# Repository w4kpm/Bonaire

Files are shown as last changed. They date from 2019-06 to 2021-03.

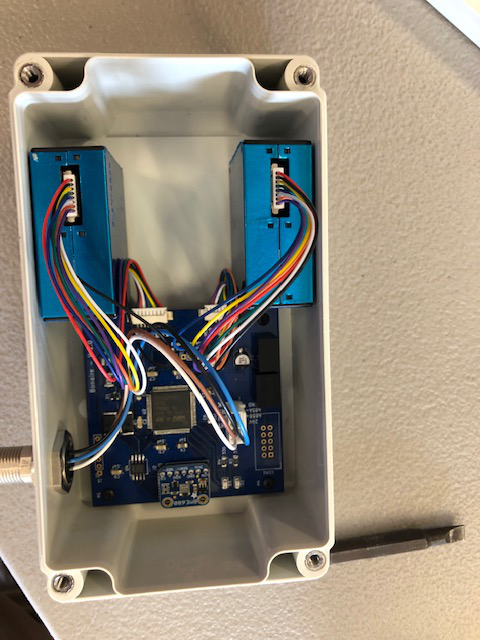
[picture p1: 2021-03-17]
IMG_2014.jpg

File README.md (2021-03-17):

# Bonaire Envronmental Sensor

Particulate Sensor / Pressure /Humidity /VOC sensor

24v / Modbus - inital modbusid = 65 baud = 9600

uses low cost BME680 for pressure, humidity, temp and voc
it also uses 2x pms5003 to measure particulate matter

details about the parameters are in the PDF's of the individual sensors

RS-485 and 24v are hooked up by 1 M12 connector 

modbus registers:

   1: pressure
    
   2: humidity
    
   3: a_pm1_0_atm
    
   4: a_pm2_5_atm
    
   5: a_pm10_0_atm
    
   6: a_pm1_0_cf_1
    
   7: a_pm2_5_cf_1
    
   8: a_pm10_0_cf_1
    
   9: a_p_0_3_um
   
   10: a_p_0_5_um
   
   11: a_p_1_0_um
   
   12: a_p_2_5_um
   
   13: a_p_5_0_um
   
   14: a_p_10_0_um
   
   15: b_pm1_0_atm
   
   16: b_pm2_5_atm
   
   17: b_pm10_0_atm
   
   18: b_pm1_0_cf_1
   
   19: b_pm2_5_cf_1
   
   20: b_pm10_0_cf_1
   
   21: b_p_0_3_um
   
   22: b_p_0_5_um
   
   23: b_p_1_0_um
   
   24: b_p_2_5_um
   
   25: b_p_5_0_um
   
   26: b_p_10_0_um
   
   27: voc
   
   28: temp

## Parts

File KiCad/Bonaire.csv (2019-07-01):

Item | Qty | Reference(s) | Value | LibPart | Footprint | Datasheet
1 | 1 | C1 | 100uF | device:CP1 | Capacitors_SMD:C_1206_HandSoldering
2 | 4 | C2, C4, C6, C8 | 1uF | device:C | Capacitors_SMD:C_1206_HandSoldering
3 | 4 | C3, C5, C7, C9 | .1uF | device:C | Capacitors_SMD:C_1206_HandSoldering
4 | 1 | C10 | .1u | device:C | Capacitors_SMD:C_1206_HandSoldering
5 | 10 | C11, C12, C14, C15, C17, C18, C20, C21, C23, C24 | .1 uF | device:C | Capacitors_SMD:C_1206_HandSoldering
6 | 5 | C13, C16, C19, C22, C25 | 100nF | device:C | Capacitors_SMD:C_1206_HandSoldering
7 | 1 | CON1 | AVR-JTAG-10 | atmel:AVR-JTAG-10 | Pin_Headers:Pin_Header_Straight_2x05_Pitch2.54mm
8 | 8 | D1, D2, D4, D5, D6, D7, D8, D9 | D_Schottky | device:D_Schottky | Diodes_SMD:D_1206
9 | 1 | D3 | D_TVS_x2_AAC | device:D_TVS_x2_AAC | TO_SOT_Packages_SMD:SOT-23_Handsoldering
10 | 4 | F1, F2, F3, F4 | Polyfuse_Small | device:Polyfuse_Small | Resistors_SMD:R_1812_HandSoldering
11 | 6 | J1, J2, J3, J4, J5, J6 | Conn_01x04 | conn:Conn_01x04
12 | 1 | J7 | Conn_01x11 | conn:Conn_01x11 | Pin_Headers:Pin_Header_Straight_1x11_Pitch2.54mm
13 | 1 | J8 | Conn_01x06 | conn:Conn_01x06 | Pin_Headers:Pin_Header_Straight_1x06_Pitch2.54mm
14 | 1 | J9 | Conn_01x09 | conn:Conn_01x09 | Pin_Headers:Pin_Header_Straight_1x09_Pitch2.54mm
15 | 1 | J10 | Conn_01x10 | conn:Conn_01x10 | Pin_Headers:Pin_Header_Straight_1x10_Pitch2.54mm
16 | 1 | J11 | Conn_01x16 | conn:Conn_01x16 | Pin_Headers:Pin_Header_Straight_2x08_Pitch2.54mm
17 | 1 | R1 | 0 | device:R | Capacitors_SMD:C_1206_HandSoldering
18 | 2 | R2, R3 | 10 | device:R | Capacitors_SMD:C_1206_HandSoldering
19 | 1 | R4 | 9k | device:R | Capacitors_SMD:C_1206_HandSoldering
20 | 1 | R5 | 125 | device:R | Capacitors_SMD:C_1206_HandSoldering
21 | 1 | R6 | 1k | device:R | Capacitors_SMD:C_1206_HandSoldering
22 | 1 | R7 | 10k | device:R | Capacitors_SMD:C_1206_HandSoldering
23 | 5 | R8, R9, R10, R11, R12 | 430 .1% | device:R | Capacitors_SMD:C_1206_HandSoldering
24 | 2 | RV1, RV2 | Varistor | device:Varistor | Resistors_SMD:R_1210_HandSoldering
25 | 1 | U1 | LM78l33_TO220 | regul:LM7812_TO220 | TO_SOT_Packages_THT:TO-220-3_Vertical
26 | 1 | U2 | STM32F303V(B-C)Tx_u | stm32:STM32F303V(B-C)Tx_u | Housings_QFP:LQFP-100_14x14mm_Pitch0.5mm
27 | 1 | U3 | SN65HV7X | MyParts:SN65HV7X | Housings_SOIC:SO-8_5.3x6.2mm_Pitch1.27mm
28 | 5 | U4, U5, U6, U7, U8 | MAX31865 | MyParts:MAX31865 | Housings_SSOP:SSOP-20_5.3x7.2mm_Pitch0.65mm

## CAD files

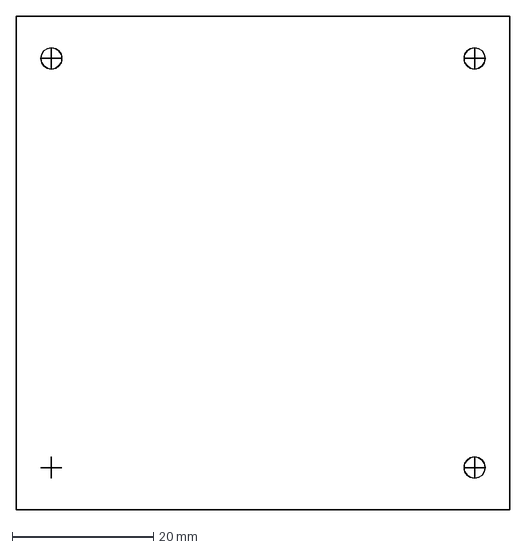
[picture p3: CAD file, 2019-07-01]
KiCad/BonaireOutline.dxf
70.0 x 70.0 mm

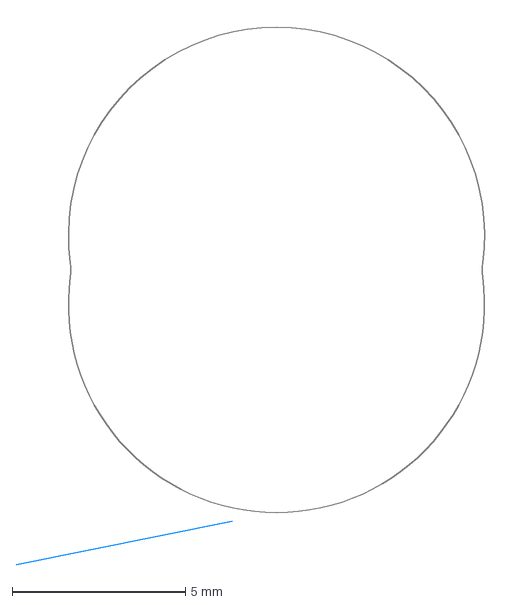
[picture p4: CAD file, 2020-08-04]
M12Hole.dxf
13.8 x 15.8 mm

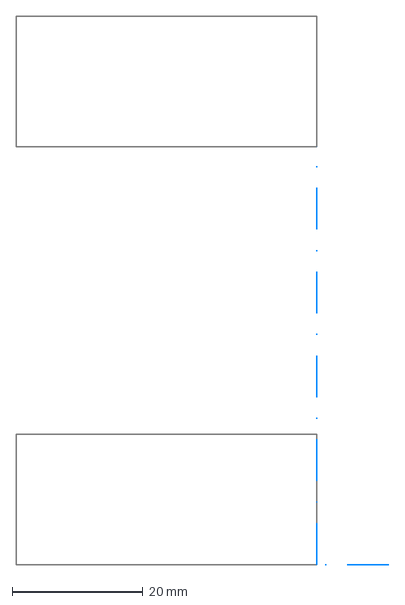
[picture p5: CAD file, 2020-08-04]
SensorCut.dxf
57.0 x 84.0 mm

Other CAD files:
KiCad/kicad-footprints/Sources/Package_SON/X2SON-4_1x1mm_P0.65mm.fcstd
KiCad/kicad-footprints/Sources/Package_TO_SOT_THT/sod-70.fcstd
KiCad/kicad-footprints/Sources/Package_TO_SOT_THT/sod-70_P5.08mm.fcstd

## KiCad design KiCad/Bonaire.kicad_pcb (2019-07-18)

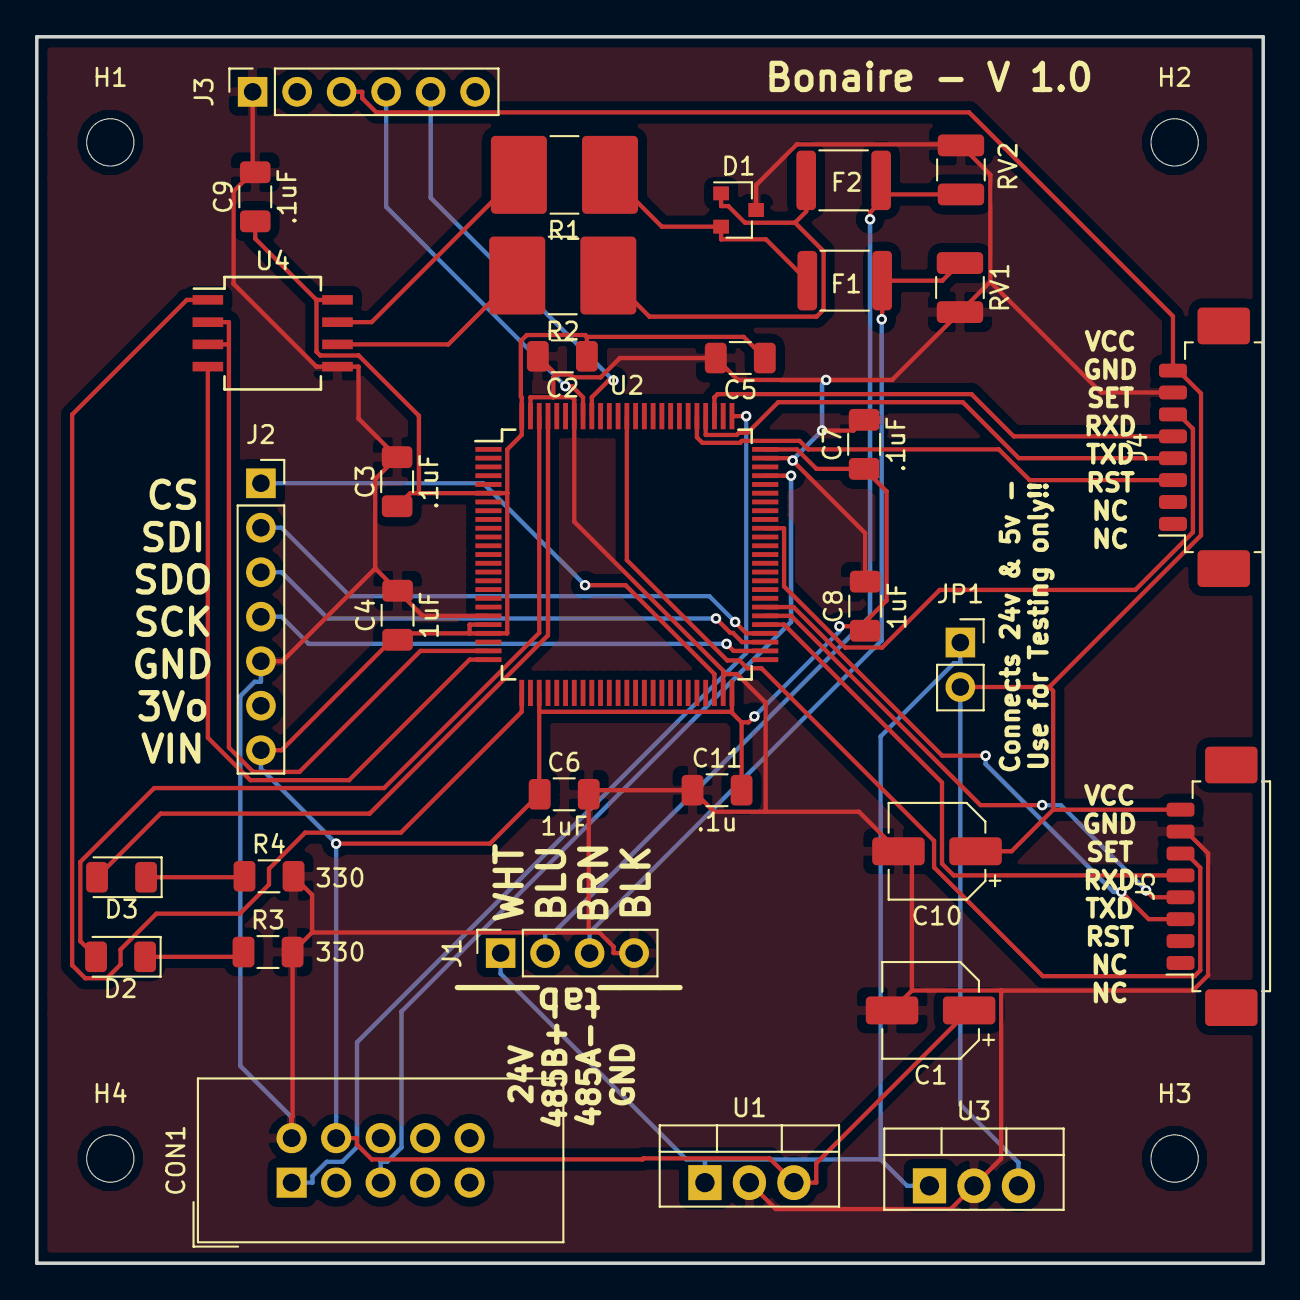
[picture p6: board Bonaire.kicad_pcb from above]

Board: 2 copper layers, 70.0 x 70.0 mm, 37 parts (0 on the bottom side), 33 nets.

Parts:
C1, C10: 100uF; CP_Elec_5x5.3
C2, C4, C6, C8: 1uF; C_1206_3216Metric
C3, C5, C7, C9: .1uF; C_1206_3216Metric
C11: .1u; C_1206_3216Metric
CON1: AVR-JTAG-10; IDC-Header_2x05_P2.54mm_Vertical
D1: D_TVS_x2_AAC; SOT-23
D2, D3: LED; LED_1206_3216Metric
F1, F2: Polyfuse_Small; R_1812_4532Metric
H1, H2, H3, H4: MountingHole; MountingHole_2.7mm_M2.5
J1: Conn_01x04; PinSocket_1x04_P2.54mm_Vertical
J2: Conn_01x07; PinSocket_1x07_P2.54mm_Vertical
J3: Conn_01x06; PinSocket_1x06_P2.54mm_Vertical
J4, J5: Conn_01x08; Molex_PicoBlade_53261-0871_1x08-1MP_P1.25mm_Horizontal
JP1: Jumper; PinSocket_1x02_P2.54mm_Vertical
R1, R2: 10; R_2816_7142Metric_Pad3.20x4.45mm_HandSolder
R3, R4: 330; R_1206_3216Metric
RV1, RV2: Varistor; R_1210_3225Metric
U1: LM78l33_TO220; TO-220-3_Vertical
U2: STM32F303V(B-C)Tx_u; LQFP-100_14x14mm_P0.5mm
U3: LM78l50_TO220; TO-220-3_Vertical
U4: SN65HV7X; SO-8_5.3x6.2mm_P1.27mm

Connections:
+3V3: C1.1, C2.1, C3.1, C4.1, C5.1, C6.1, C7.1, C8.1, C9.1, C11.2, CON1.4, J2.7, U1.3, U2.6, U2.21, U2.22, U2.28, U2.50, U2.75, U2.100, U4.8
+5V: C10.1, J3.3, J4.8, J5.8, JP1.2, U3.3
+24V: J1.1, JP1.1, U1.1, U3.1
/GPIOA/serial/RX: U2.26, U4.1
/GPIOA/serial/TX: U2.25, U4.4
/GPIOA/serial/TX_en: U2.24, U4.2, U4.3
/GPIOB/MISO: J2.3, U2.53
/GPIOB/MOSI: J2.2, U2.54
/GPIOB/SCK: J2.4, U2.52
/GPIOB/UART1_RX: J3.4, U2.93
/GPIOB/UART1_TX: J3.5, U2.92
/GPIOB/~CS: J2.1, U2.48
/RS485A: F2.1, J1.2, RV2.1
/RS485B: F1.1, J1.3, RV1.1
GND: C1.2, C2.2, C3.2, C4.2, C5.2, C6.2, C7.2, C8.2, C9.2, C10.2, C11.1, CON1.2, D1.3, J1.4, J2.5, J3.1, J4.7, J5.7, R3.2, R4.2, RV1.2, RV2.2, U1.2, U2.20, U2.49, U2.74, U2.94, U2.99, U3.2, U4.5
unnamed: CON1.1, U2.76
unnamed: CON1.5, U2.72
unnamed: D1.1, F2.2, R2.1
unnamed: D1.2, F1.2, R1.1
unnamed: D2.1, R3.1
unnamed: D2.2, U2.98
unnamed: D3.1, R4.1
unnamed: D3.2, U2.97
unnamed: J4.3, U2.80
unnamed: J4.4, U2.79
unnamed: J4.5, U2.78
unnamed: J4.6, U2.66
unnamed: J5.3, U2.57
unnamed: J5.4, U2.56
unnamed: J5.5, U2.55
unnamed: J5.6, U2.88
unnamed: R1.2, U4.7
unnamed: R2.2, U4.6

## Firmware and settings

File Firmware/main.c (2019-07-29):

// internal reference voltage calibration  0x1FFF F7BA - 0x1FFF F7BB

// TS_CAL1 TS_CAL2 = 0x1FFF F7B8 - 0x1FFF F7B9 and 0x1FFF F7C2 - 0x1FFF F7C3




/*
    ChibiOS - Copyright (C) 2006..2015 Giovanni Di Sirio

    Licensed under the Apache License, Version 2.0 (the "License");
    you may not use this file except in compliance with the License.
    You may obtain a copy of the License at

        http://www.apache.org/licenses/LICENSE-2.0

    Unless required by applicable law or agreed to in writing, software
    distributed under the License is distributed on an "AS IS" BASIS,
    WITHOUT WARRANTIES OR CONDITIONS OF ANY KIND, either express or implied.
    See the License for the specific language governing permissions and
    limitations under the License.
*/

#define CHPRINTF_USE_FLOAT   TRUE
#include "ch.h"
#include "hal.h"
#include "stdio.h"
#include "string.h"
#include "stdlib.h"
#include "math.h"
//#include "chprintf.h"
#include "hal_queues.h"
#include <string.h>
#include "stm32f3xx.h"
//#include "font.h"
//#include "fontbig.h"
#include "bme680.h"


static uint8_t txbuf[32];
static uint8_t rxbuf[32];
static uint8_t my_address;
static uint8_t save_address;
static uint8_t baud_rate;
static uint8_t save_baud_rate;
static uint8_t reset =0;

static char text[255];
static char metrics[9][12];

static uint8_t vbuf2[32][33];
static uint8_t vbuf[32][33];


static uint16_t *flash1 = 0x803F000;
static uint16_t *flash2 = 0x803e800;
static uint16_t settings;


static  uint16_t a_pm1_0_atm,
  a_pm2_5_atm,
  a_pm10_0_atm,
  a_pm1_0_cf_1,
  a_pm2_5_cf_1,
  a_pm10_0_cf_1,
  a_p_0_3_um,
  a_p_0_5_um,
  a_p_1_0_um,
  a_p_2_5_um,
  a_p_5_0_um,
  a_p_10_0_um;


static  uint16_t b_pm1_0_atm,
  b_pm2_5_atm,
  b_pm10_0_atm,
  b_pm1_0_cf_1,
  b_pm2_5_cf_1,
  b_pm10_0_cf_1,
  b_p_0_3_um,
  b_p_0_5_um,
  b_p_1_0_um,
  b_p_2_5_um,
  b_p_5_0_um,
  b_p_10_0_um;

static uint16_t humidity,pressure,voc,temp;


#define ADC_GRP1_NUM_CHANNELS   2
#define ADC_GRP2_NUM_CHANNELS   6
#define ADC_GRP1_BUF_DEPTH      1
#define ADC_GRP2_BUF_DEPTH      1
static adcsample_t samples1[ADC_GRP1_NUM_CHANNELS * ADC_GRP1_BUF_DEPTH];
static adcsample_t samples2[ADC_GRP2_NUM_CHANNELS * ADC_GRP2_BUF_DEPTH];
size_t nx = 0, ny = 0;



#define RST 12
#define SPISELECT 11
#define CK 13
#define MISO 14
#define MOSI 15
#define DC 14

struct bme680_dev gas_sensor;







static const SPIConfig std_spicfg3 = {
  NULL,
  NULL,
  GPIOB,                                                        /*port of CS  */
  SPISELECT,                                                /*pin of CS   */
  //SPI_CR1_CPOL|	SPI_CR1_CPHA |		\
  //SPI_CR1_SPE|SPI_CR1_MSTR|SPI_CR1_BR_2,SPI_CR1_BR_1,
  0,
  SPI_CR2_DS_2 | SPI_CR2_DS_1 | SPI_CR2_DS_0                    /*CR2 register*/
};




void unlock_flash()
{
    if (FLASH->CR & FLASH_CR_LOCK){
	FLASH->KEYR = 0x45670123;
	FLASH->KEYR = 0xCDEF89AB;
    }


}


void erase_flash(uint16_t *flash)
{
    int x;
    unlock_flash();                        // must unlock flash before
					   // any write operations

    FLASH->CR |= FLASH_CR_PER;             // set page erase
    
    FLASH->AR = flash;                     // set page to flash
    
    FLASH->CR |= FLASH_CR_STRT;            // start erasing
    
    while ((FLASH->SR & FLASH_SR_BSY) == FLASH_SR_BSY); // loop till done
							// watchdog should
							// reset if it gets
							// stuck

    SET_BIT (FLASH->SR, (FLASH_SR_EOP));   // tech note RM0316 says to clear
    CLEAR_BIT (FLASH->CR, (FLASH_CR_PER)); // found note online that you must
                                           // clear this prior to writing
    
}


void write_flash(uint16_t value,uint16_t* flash)
{
    int x;
    erase_flash(flash);


      
    SET_BIT(FLASH->CR, (FLASH_CR_PG));     // we are already unlocked, trying
					   // to do it again will mess
					   // things up
    
    *flash = value;                        // actually write the value

    
    while ((FLASH->SR & FLASH_SR_BSY) == FLASH_SR_BSY); // loop till done
							// watchdog should
							// reset if it gets
							// stuck
    //  CLEAR_BIT (FLASH->CR, (FLASH_CR_PG));  // probably don't need to to this
					   // again
    
    //SET_BIT (FLASH->SR, (FLASH_SR_EOP));   // tech note RM0316 says to clear
    FLASH->CR |= FLASH_CR_LOCK;
}










void spi_write(location,data)
{
  //palClearPad(GPIOB,SPISELECT);
    spiStart(&SPID2,&std_spicfg3);
    spiSelect(&SPID2);
    txbuf[0] = location;
    txbuf[1] = data;
    spiSend(&SPID2,2,&txbuf);
    spiUnselect(&SPID2);
    spiStop(&SPID2);
    //palSetPad(GPIOB,SPISELECT);
}

uint8_t spi_read(location)
{
  //    palClearPad(GPIOB,SPISELECT);
    spiStart(&SPID2,&std_spicfg3);
    spiSelect(&SPID2);
    txbuf[0] = location | 0x80;
    spiSend(&SPID2,1,&txbuf);
    spiReceive(&SPID2,1,&rxbuf);
    spiUnselect(&SPID2);
    spiStop(&SPID2);
    //   palSetPad(GPIOB,SPISELECT);
    return rxbuf[0];
}


void init_spi()
{

  //  palSetPadMode(GPIOB, RST, PAL_MODE_OUTPUT_PUSHPULL);
  //palSetPadMode(GPIOB, DC, PAL_MODE_OUTPUT_PUSHPULL);
  palSetPadMode(GPIOB, SPISELECT, PAL_MODE_OUTPUT_PUSHPULL);
  palSetPad(GPIOB,SPISELECT);
  //palSetPad(GPIOB,RST);

}










// this should set a timeout of .625 seconds (LSI = 40k / (64 * 1000))

static const WDGConfig wdgcfg = {
  STM32_IWDG_PR_64,
  STM32_IWDG_RL(2000),
  STM32_IWDG_WIN_DISABLED};

// This got redefined in a later version of Chibios for this board
#define GPIOA_PIN0 0



//static uint8_t vbuf[64][128];
//static uint8_t vbuf2[64][128];

static mailbox_t RxMbx;
static mailbox_t RxMbx2;
static mailbox_t RxMbx3;
#define MAILBOX_SIZE 25
static msg_t RxMbxBuff[MAILBOX_SIZE];
static msg_t RxMbxBuff2[MAILBOX_SIZE];
static msg_t RxMbxBuff3[MAILBOX_SIZE];
static char current_key;
static  uint16_t step =0;
static  int16_t deg,speed =0;

static char rx_text[32][48];
static char rx_text2[8][48];
static char rx_text3[8][48];
static int8_t heatValue;
static uint8_t res_heat_x;
static uint8_t heatRange;
static double par_g1,par_g2,par_g3,var1,var2,var3,var4,var5,target_temp,amb_temp,res_heat_range,res_heat_val;
static SerialConfig uartCfg =
{
    115200,// bit rate
    0,
    0,
    0,
};


//static SerialConfig uartCfg2 =
//{
//    19200,// bit rate
//    0x1400,
//    0,
//    0,
//};
//

static SerialConfig uartCfg2 =
{
    9600,// bit rate
    0,
    0,
    0,
};



static SerialConfig uartCfg3 =
{
    19200,// bit rate
    0,
    0,
    0,
};


dbg(char *string)
{
    chprintf((BaseSequentialStream*)&SD1,string);
    chThdSleepMilliseconds(100);
}


/*
 * Application entry point.
 */


/* ******************
stolen from http://www.modbustools.com/modbus.html#crc
*/
uint16_t CRC16 (const char *nData, uint16_t wLength)
{
static const uint16_t wCRCTable[] = {
   0X0000, 0XC0C1, 0XC181, 0X0140, 0XC301, 0X03C0, 0X0280, 0XC241,
   0XC601, 0X06C0, 0X0780, 0XC741, 0X0500, 0XC5C1, 0XC481, 0X0440,
   0XCC01, 0X0CC0, 0X0D80, 0XCD41, 0X0F00, 0XCFC1, 0XCE81, 0X0E40,
   0X0A00, 0XCAC1, 0XCB81, 0X0B40, 0XC901, 0X09C0, 0X0880, 0XC841,
   0XD801, 0X18C0, 0X1980, 0XD941, 0X1B00, 0XDBC1, 0XDA81, 0X1A40,
   0X1E00, 0XDEC1, 0XDF81, 0X1F40, 0XDD01, 0X1DC0, 0X1C80, 0XDC41,
   0X1400, 0XD4C1, 0XD581, 0X1540, 0XD701, 0X17C0, 0X1680, 0XD641,
   0XD201, 0X12C0, 0X1380, 0XD341, 0X1100, 0XD1C1, 0XD081, 0X1040,
   0XF001, 0X30C0, 0X3180, 0XF141, 0X3300, 0XF3C1, 0XF281, 0X3240,
   0X3600, 0XF6C1, 0XF781, 0X3740, 0XF501, 0X35C0, 0X3480, 0XF441,
   0X3C00, 0XFCC1, 0XFD81, 0X3D40, 0XFF01, 0X3FC0, 0X3E80, 0XFE41,
   0XFA01, 0X3AC0, 0X3B80, 0XFB41, 0X3900, 0XF9C1, 0XF881, 0X3840,
   0X2800, 0XE8C1, 0XE981, 0X2940, 0XEB01, 0X2BC0, 0X2A80, 0XEA41,
   0XEE01, 0X2EC0, 0X2F80, 0XEF41, 0X2D00, 0XEDC1, 0XEC81, 0X2C40,
   0XE401, 0X24C0, 0X2580, 0XE541, 0X2700, 0XE7C1, 0XE681, 0X2640,
   0X2200, 0XE2C1, 0XE381, 0X2340, 0XE101, 0X21C0, 0X2080, 0XE041,
   0XA001, 0X60C0, 0X6180, 0XA141, 0X6300, 0XA3C1, 0XA281, 0X6240,
   0X6600, 0XA6C1, 0XA781, 0X6740, 0XA501, 0X65C0, 0X6480, 0XA441,
   0X6C00, 0XACC1, 0XAD81, 0X6D40, 0XAF01, 0X6FC0, 0X6E80, 0XAE41,
   0XAA01, 0X6AC0, 0X6B80, 0XAB41, 0X6900, 0XA9C1, 0XA881, 0X6840,
   0X7800, 0XB8C1, 0XB981, 0X7940, 0XBB01, 0X7BC0, 0X7A80, 0XBA41,
   0XBE01, 0X7EC0, 0X7F80, 0XBF41, 0X7D00, 0XBDC1, 0XBC81, 0X7C40,
   0XB401, 0X74C0, 0X7580, 0XB541, 0X7700, 0XB7C1, 0XB681, 0X7640,
   0X7200, 0XB2C1, 0XB381, 0X7340, 0XB101, 0X71C0, 0X7080, 0XB041,
   0X5000, 0X90C1, 0X9181, 0X5140, 0X9301, 0X53C0, 0X5280, 0X9241,
   0X9601, 0X56C0, 0X5780, 0X9741, 0X5500, 0X95C1, 0X9481, 0X5440,
   0X9C01, 0X5CC0, 0X5D80, 0X9D41, 0X5F00, 0X9FC1, 0X9E81, 0X5E40,
   0X5A00, 0X9AC1, 0X9B81, 0X5B40, 0X9901, 0X59C0, 0X5880, 0X9841,
   0X8801, 0X48C0, 0X4980, 0X8941, 0X4B00, 0X8BC1, 0X8A81, 0X4A40,
   0X4E00, 0X8EC1, 0X8F81, 0X4F40, 0X8D01, 0X4DC0, 0X4C80, 0X8C41,
   0X4400, 0X84C1, 0X8581, 0X4540, 0X8701, 0X47C0, 0X4680, 0X8641,
   0X8201, 0X42C0, 0X4380, 0X8341, 0X4100, 0X81C1, 0X8081, 0X4040 };

char nTemp;
uint16_t wCRCWord = 0xFFFF;

   while (wLength--)
   {
      nTemp = *nData++ ^ wCRCWord;
      wCRCWord >>= 8;
      wCRCWord  ^= wCRCTable[nTemp];
   }
   return wCRCWord;
} // End: CRC16




// Modbus Serial Capture
static THD_WORKING_AREA(waThread3, 512);
static THD_FUNCTION(Thread3, arg) {
  (void)arg;
  int pass = 0;
  msg_t b = 0;
  int rx_queue_pos=0;
  int rx_queue_num=0;

  chRegSetThreadName("serial");
  while(TRUE)
      {
	  
	  b = sdGetTimeout(&SD2,TIME_MS2I(2));

	  if ((b!= Q_TIMEOUT) && (rx_queue_pos < 32))
	      {
		
		  rx_text[rx_queue_num][rx_queue_pos++]=b;
	       
		
	      }
	  if ((b == Q_TIMEOUT) && (rx_queue_pos > 0))
	      {

		  rx_text[rx_queue_num][rx_queue_pos] = 0;
		  chprintf((BaseSequentialStream*)&SD1,"sent One: %d,%d\r\n",rx_queue_num,rx_queue_pos);  
		  chMBPostTimeout(&RxMbx,(rx_queue_num<<8)|rx_queue_pos,TIME_INFINITE); // let our mailbox know
		  chMBPostTimeout(&RxMbx2,(rx_queue_num<<8),TIME_INFINITE); // let our mailbox know
		  rx_queue_pos = 0;
		  // we have a new entry
		  rx_queue_num = (++rx_queue_num)%32;
		  memset(rx_text[rx_queue_num],0,5);
	      }
	  
  
      }

  return MSG_OK;
}

// Particulate Sensor 1 capture
static THD_WORKING_AREA(waThread6, 512);
static THD_FUNCTION(Thread6, arg) {
  (void)arg;
  int pass = 0;
  msg_t b = 0;
  int rx_queue_pos=0;
  int rx_queue_num=0;

  chRegSetThreadName("part1");
  while(TRUE)
      {
	  
	  b = sdGetTimeout(&SD3,TIME_MS2I(5));


	  if ((b!= Q_TIMEOUT) && (rx_queue_pos < 32))
	      {
		
		//chprintf((BaseSequentialStream*)&SD2,"got char: %x\r\n",b);

		rx_text2[rx_queue_num][rx_queue_pos++]=b;
		
		
		

		
	      }
	  if ((b == Q_TIMEOUT) && (rx_queue_pos > 0))
	      {

		  rx_text2[rx_queue_num][rx_queue_pos] = 0;

		  chMBPostTimeout(&RxMbx3,(rx_queue_num<<8),TIME_INFINITE); // let our mailbox know
		  //chMBPostTimeout(&RxMbx2,(rx_queue_num<<8),TIME_INFINITE); // let our mailbox know
		  rx_queue_pos = 0;
		  // we have a new entry
		  rx_queue_num = (++rx_queue_num)%8;
		  memset(rx_text2[rx_queue_num],0,5);
	      }
	  
  
      }

  return MSG_OK;
}

// Particulate Sensor 2 capture
static THD_WORKING_AREA(waThread7, 512);
static THD_FUNCTION(Thread7, arg) {
  (void)arg;
  int pass = 0;
  msg_t b = 0;
  int rx_queue_pos=0;
  int rx_queue_num=0;

  chRegSetThreadName("part2");
  while(TRUE)
      {
	  
	  b = sdGetTimeout(&SD4,TIME_MS2I(5));


	  if ((b!= Q_TIMEOUT) && (rx_queue_pos < 32))
	      {

		  rx_text3[rx_queue_num][rx_queue_pos++]=b;		
	      }
	  if ((b == Q_TIMEOUT) && (rx_queue_pos > 0))
	      {

		  rx_text3[rx_queue_num][rx_queue_pos] = 0;
		  chMBPostTimeout(&RxMbx3,(rx_queue_num<<8)|0x1,TIME_INFINITE); // let our mailbox know
		  rx_queue_pos = 0;
		  // we have a new entry
		  rx_queue_num = (++rx_queue_num)%8;
		  memset(rx_text3[rx_queue_num],0,5);
	      }
	  
  
      }

  return MSG_OK;
}
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
int main(void) {
  unsigned i;

  /*
   * System initializations.
   * - HAL initialization, this also initializes the configured device drivers
   *   and performs the board-specific initializations.
   * - Kernel initialization, the main() function becomes a thread and the
   *   RTOS is active.
   */
  halInit();
  chSysInit();
 

  
  palSetPad(GPIOB, 5);
  wdgStart(&WDGD1, &wdgcfg);
  wdgReset(&WDGD1);
  chMBObjectInit(&RxMbx,&RxMbxBuff,MAILBOX_SIZE);
  chMBObjectInit(&RxMbx2,&RxMbxBuff2,MAILBOX_SIZE);
  chMBObjectInit(&RxMbx3,&RxMbxBuff3,MAILBOX_SIZE);
  adcStart(&ADCD1, NULL);
  //  adcStart(&ADCD4, NULL);
  // I think this needs to go after the start - even though it worked fine before

  // I had a problem in another context
  adcSTM32EnableTSVREFE();
  adcSTM32EnableTS(&ADCD1);
  



  /*
   * SPI1 I/O pins setup.
   */



  palSetPadMode(GPIOE, 0, PAL_MODE_OUTPUT_PUSHPULL);
  palSetPadMode(GPIOE, 1, PAL_MODE_OUTPUT_PUSHPULL);    

  palSetPadMode(GPIOB, 6, PAL_MODE_ALTERNATE(7));  //USART1 - console  
  palSetPadMode(GPIOB, 7, PAL_MODE_ALTERNATE(7));
  palSetPadMode(GPIOA, 1, PAL_MODE_OUTPUT_PUSHPULL); // tx/rx
  palSetPadMode(GPIOA, 2, PAL_MODE_ALTERNATE(7));  //USART2 - MODBUS
  palSetPadMode(GPIOA, 3, PAL_MODE_ALTERNATE(7));

  palSetPadMode(GPIOD, 8, PAL_MODE_ALTERNATE(7));  //USART3 - particle sensor
  palSetPadMode(GPIOD, 9, PAL_MODE_ALTERNATE(7));


  palSetPadMode(GPIOC, 10, PAL_MODE_ALTERNATE(5));  //USART4 - particle sensor
  palSetPadMode(GPIOC, 11, PAL_MODE_ALTERNATE(5));

  
  palSetPadMode(GPIOB, 11, PAL_MODE_OUTPUT_PUSHPULL);      // spi2

  palSetPadMode(GPIOB, 15, PAL_MODE_ALTERNATE(5)|PAL_STM32_OSPEED_HIGHEST);
  palSetPadMode(GPIOB, 14, PAL_MODE_ALTERNATE(5)|PAL_STM32_OSPEED_HIGHEST);
  palSetPadMode(GPIOB, 13, PAL_MODE_ALTERNATE(5)|PAL_STM32_OSPEED_HIGHEST);


  
  sdStart(&SD1,&uartCfg);
  sdStart(&SD3,&uartCfg2);
  sdStart(&SD4,&uartCfg2);

  


  if (*flash1 == 0xffff){
      my_address = 65; // if flash hasn't been set up yet we default to
                       // id 60, baud 9600
      baud_rate=0;
      chprintf((BaseSequentialStream*)&SD1,"Resetting Flash - I am # %d,%d\r\n",my_address,baud_rate);
      write_flash((my_address&0xff),flash1);
      chprintf((BaseSequentialStream*)&SD1,"ReadingFlash - I have # %x\r\n",*flash1);
  }
  else{
      // flash has been written - use those values
      // init saved values in case we only choose to reset
      // just id or just address later.
      my_address = (*flash1) & 0xff;
      save_address = my_address;
      baud_rate = ((*flash1) & 0xff00) >> 8;
      save_baud_rate = baud_rate;

  }

      



  restart_modbus();
  chprintf((BaseSequentialStream*)&SD1,"Hello World - I am # %d,%d\r\n",my_address,baud_rate);
  palSetPad(GPIOA, 1);     // Recieve Enable RS485
  //chprintf((BaseSequentialStream*)&SD2,"modbuschannel\r\n");

  init_spi();
  chprintf((BaseSequentialStream*)&SD1,"SPI init\r\n");
  
  palSetPad(GPIOE, 0);     // Disable TX Light
  palSetPad(GPIOE, 1);     // Disable RX Light


  
  feedWatchdog();
  chThdSleepMilliseconds(1000);
  palClearPad(GPIOA, 1);     // Recieve Enable RS485
  palClearPad(GPIOE, 0);     // Disable TX Light
  palClearPad(GPIOE, 1);     // Disable RX Light
  feedWatchdog();
  chThdSleepMilliseconds(1000);
  feedWatchdog();


  chThdCreateStatic(waThread1, sizeof(waThread1), NORMALPRIO, Thread1, NULL);
  chprintf((BaseSequentialStream*)&SD1,"HelloA\r\n")  ;
  chThdCreateStatic(waThread3, sizeof(waThread3), NORMALPRIO, Thread3, NULL);
  chprintf((BaseSequentialStream*)&SD1,"HelloB\r\n")  ;
  chThdCreateStatic(waThread4, sizeof(waThread4), NORMALPRIO, Thread4, NULL);
  chprintf((BaseSequentialStream*)&SD1,"HelloC\r\n")  ;
  chThdCreateStatic(waThread5, sizeof(waThread5), NORMALPRIO, Thread5, NULL);
  chThdCreateStatic(waThread6, sizeof(waThread6), NORMALPRIO, Thread6, NULL);
  chThdCreateStatic(waThread7, sizeof(waThread7), NORMALPRIO, Thread7, NULL);

;  
  uint32_t x,y;
  float VDD;
  float outsideTemp;
  float internalTemp;
  

  //Default OPAMP4 CSR 10880000
  
  gas_sensor.dev_id = 0;
  gas_sensor.intf = BME680_SPI_INTF;
  gas_sensor.read = user_spi_read;
  gas_sensor.write = user_spi_write;
  gas_sensor.delay_ms = user_delay_ms;
  gas_sensor.amb_temp = 25;
  int8_t rslt = BME680_OK;

rslt = bme680_init(&gas_sensor);

    gas_sensor.tph_sett.os_hum = BME680_OS_2X;
    gas_sensor.tph_sett.os_pres = BME680_OS_4X;
    gas_sensor.tph_sett.os_temp = BME680_OS_8X;
    gas_sensor.tph_sett.filter = BME680_FILTER_SIZE_3;

    /* Set the remaining gas sensor settings and link the heating profile */
    gas_sensor.gas_sett.run_gas = BME680_ENABLE_GAS_MEAS;
    /* Create a ramp heat waveform in 3 steps */
    gas_sensor.gas_sett.heatr_temp = 320; /* degree Celsius */
    gas_sensor.gas_sett.heatr_dur = 150; /* milliseconds */

    /* Select the power mode */
    /* Must be set before writing the sensor configuration */


  
  



    while (TRUE)
      {
	  feedWatchdog();

	  step = (step +1)%288;
	 
	  feedWatchdog();


	  // datasheet RM0316 VDDA = 3.3 V ₓ VREFINT_CAL / VREFINT_DATA
	  
	  //chprintf(&SD1,"calibrated at 3.3 %d\r\n",*(uint16_t*)0x1FFFF7BA);
	  //chprintf((BaseSequentialStream*)&SD1,"ADC4 %d %d %d %d %d\r\n",samples2[0],samples2[1],samples2[2],samples2[3],samples2[4]);
	  chThdSleepMilliseconds(1000);
    gas_sensor.power_mode = BME680_FORCED_MODE; 

    /* Set the required sensor settings needed */
    set_required_settings = BME680_OST_SEL | BME680_OSP_SEL | BME680_OSH_SEL | BME680_FILTER_SEL 
        | BME680_GAS_SENSOR_SEL;

	  /* Set the desired sensor configuration */
    rslt = bme680_set_sensor_settings(set_required_settings,&gas_sensor);

    /* Set the power mode */
    rslt = bme680_set_sensor_mode(&gas_sensor);
	  
	  rslt = bme680_get_sensor_data(&data, &gas_sensor);
	  chprintf(&SD1,"T: %.2f degC, P: %.2f hPa, H %.2f %%rH ", data.temperature / 100.0f,
            data.pressure / 100.0f, data.humidity / 1000.0f );
	  pressure = data.pressure/10;
	  humidity = data.humidity/10;
	  temp = data.temperature/10;
        /* Avoid using measurements from an unstable heating setup */
        if(data.status & BME680_GASM_VALID_MSK)
	  chprintf(&SD1,", G: %d ohms", data.gas_resistance);
	voc = data.gas_resistance/10;
	
	chprintf(&SD1,"\r\n");
	
       }

  return 0;
}

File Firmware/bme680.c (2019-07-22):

/**\mainpage
 * Copyright (C) 2017 - 2018 Bosch Sensortec GmbH
 *
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
 * Redistributions of source code must retain the above copyright
 * notice, this list of conditions and the following disclaimer.
 *
 * Redistributions in binary form must reproduce the above copyright
 * notice, this list of conditions and the following disclaimer in the
 * documentation and/or other materials provided with the distribution.
 *
 * Neither the name of the copyright holder nor the names of the
 * contributors may be used to endorse or promote products derived from
 * this software without specific prior written permission.
 *
 * THIS SOFTWARE IS PROVIDED BY THE COPYRIGHT HOLDERS AND
 * CONTRIBUTORS "AS IS" AND ANY EXPRESS OR
 * IMPLIED WARRANTIES, INCLUDING, BUT NOT LIMITED TO, THE IMPLIED
 * WARRANTIES OF MERCHANTABILITY AND FITNESS FOR A PARTICULAR PURPOSE ARE
 * DISCLAIMED. IN NO EVENT SHALL COPYRIGHT HOLDER
 * OR CONTRIBUTORS BE LIABLE FOR ANY
 * DIRECT, INDIRECT, INCIDENTAL, SPECIAL, EXEMPLARY,
 * OR CONSEQUENTIAL DAMAGES(INCLUDING, BUT NOT LIMITED TO,
 * PROCUREMENT OF SUBSTITUTE GOODS OR SERVICES;
 * LOSS OF USE, DATA, OR PROFITS; OR BUSINESS INTERRUPTION)
 * HOWEVER CAUSED AND ON ANY THEORY OF LIABILITY,
 * WHETHER IN CONTRACT, STRICT LIABILITY, OR TORT
 * (INCLUDING NEGLIGENCE OR OTHERWISE) ARISING IN
 * ANY WAY OUT OF THE USE OF THIS
 * SOFTWARE, EVEN IF ADVISED OF THE POSSIBILITY OF SUCH DAMAGE
 *
 * The information provided is believed to be accurate and reliable.
 * The copyright holder assumes no responsibility
 * for the consequences of use
 * of such information nor for any infringement of patents or
 * other rights of third parties which may result from its use.
 * No license is granted by implication or otherwise under any patent or
 * patent rights of the copyright holder.
 *
 * File		bme680.c
 * @date	19 Jun 2018
 * @version	3.5.9
 *
 */

/*! @file bme680.c
 @brief Sensor driver for BME680 sensor */
#include "bme680.h"
#include <stdio.h>
/*!
 * @brief This internal API is used to read the calibrated data from the sensor.
 *
 * This function is used to retrieve the calibration
 * data from the image registers of the sensor.
 *
 * @note Registers 89h  to A1h for calibration data 1 to 24
 *        from bit 0 to 7
 * @note Registers E1h to F0h for calibration data 25 to 40
 *        from bit 0 to 7
 * @param[in] dev	:Structure instance of bme680_dev.
 *
 * @return Result of API execution status.
 * @retval zero -> Success / +ve value -> Warning / -ve value -> Error
 */
static int8_t get_calib_data(struct bme680_dev *dev);

/*!
 * @brief This internal API is used to set the gas configuration of the sensor.
 *
 * @param[in] dev	:Structure instance of bme680_dev.
 *
 * @return Result of API execution status.
 * @retval zero -> Success / +ve value -> Warning / -ve value -> Error
 */
static int8_t set_gas_config(struct bme680_dev *dev);

/*!
 * @brief This internal API is used to get the gas configuration of the sensor.
 * @note heatr_temp and heatr_dur values are currently register data
 * and not the actual values set
 *
 * @param[in] dev	:Structure instance of bme680_dev.
 *
 * @return Result of API execution status.
 * @retval zero -> Success / +ve value -> Warning / -ve value -> Error
 */
static int8_t get_gas_config(struct bme680_dev *dev);

/*!
 * @brief This internal API is used to calculate the Heat duration value.
 *
 * @param[in] dur	:Value of the duration to be shared.
 *
 * @return uint8_t threshold duration after calculation.
 */
static uint8_t calc_heater_dur(uint16_t dur);

#ifndef BME680_FLOAT_POINT_COMPENSATION

/*!
 * @brief This internal API is used to calculate the temperature value.
 *
 * @param[in] dev	:Structure instance of bme680_dev.
 * @param[in] temp_adc	:Contains the temperature ADC value .
 *
 * @return uint32_t calculated temperature.
 */
static int16_t calc_temperature(uint32_t temp_adc, struct bme680_dev *dev);

/*!
 * @brief This internal API is used to calculate the pressure value.
 *
 * @param[in] dev	:Structure instance of bme680_dev.
 * @param[in] pres_adc	:Contains the pressure ADC value .
 *
 * @return uint32_t calculated pressure.
 */
static uint32_t calc_pressure(uint32_t pres_adc, const struct bme680_dev *dev);

/*!
 * @brief This internal API is used to calculate the humidity value.
 *
 * @param[in] dev	:Structure instance of bme680_dev.
 * @param[in] hum_adc	:Contains the humidity ADC value.
 *
 * @return uint32_t calculated humidity.
 */
static uint32_t calc_humidity(uint16_t hum_adc, const struct bme680_dev *dev);

/*!
 * @brief This internal API is used to calculate the Gas Resistance value.
 *
 * @param[in] dev		:Structure instance of bme680_dev.
 * @param[in] gas_res_adc	:Contains the Gas Resistance ADC value.
 * @param[in] gas_range		:Contains the range of gas values.
 *
 * @return uint32_t calculated gas resistance.
 */
static uint32_t calc_gas_resistance(uint16_t gas_res_adc, uint8_t gas_range, const struct bme680_dev *dev);

/*!
 * @brief This internal API is used to calculate the Heat Resistance value.
 *
 * @param[in] dev	: Structure instance of bme680_dev
 * @param[in] temp	: Contains the target temperature value.
 *
 * @return uint8_t calculated heater resistance.
 */
static uint8_t calc_heater_res(uint16_t temp, const struct bme680_dev *dev);

#else
/*!
 * @brief This internal API is used to calculate the
 * temperature value value in float format
 *
 * @param[in] dev	:Structure instance of bme680_dev.
 * @param[in] temp_adc	:Contains the temperature ADC value .
 *
 * @return Calculated temperature in float
 */
static float calc_temperature(uint32_t temp_adc, struct bme680_dev *dev);

/*!
 * @brief This internal API is used to calculate the
 * pressure value value in float format
 *
 * @param[in] dev	:Structure instance of bme680_dev.
 * @param[in] pres_adc	:Contains the pressure ADC value .
 *
 * @return Calculated pressure in float.
 */
static float calc_pressure(uint32_t pres_adc, const struct bme680_dev *dev);

/*!
 * @brief This internal API is used to calculate the
 * humidity value value in float format
 *
 * @param[in] dev	:Structure instance of bme680_dev.
 * @param[in] hum_adc	:Contains the humidity ADC value.
 *
 * @return Calculated humidity in float.
 */
static float calc_humidity(uint16_t hum_adc, const struct bme680_dev *dev);

/*!
 * @brief This internal API is used to calculate the
 * gas resistance value value in float format
 *
 * @param[in] dev		:Structure instance of bme680_dev.
 * @param[in] gas_res_adc	:Contains the Gas Resistance ADC value.
 * @param[in] gas_range		:Contains the range of gas values.
 *
 * @return Calculated gas resistance in float.
 */
static float calc_gas_resistance(uint16_t gas_res_adc, uint8_t gas_range, const struct bme680_dev *dev);
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

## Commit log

2019-06-24 initial add - stolen from Helios
    [stm_spc56ec74a256s_spc56ec74_minimodule_debug_jtag.cfg, stm_xpc560b64_minimodule_debug_jtag.cfg, stm_xpc560b_spc560d40_minimodule_debug_jtag.cfg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]
2019-06-24 Reading the first particulate sensor
2019-07-01 Added Board code to repository
    [Bonaire.csv, Bonaire.dsn, Bonaire.kicad_pcb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]
2019-07-01 add extra kicad directory
2019-07-01 revised Schematic for Beta version of Bonaire
    [Bonaire.sch, GPIOA.sch, GPIOB.sch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]
2019-07-01 Have board layout done, need to route
    [Bonaire.kicad_pcb, Bonaire.sch, BonaireOutline.dxf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]
2019-07-08 Add Last send of Circuit board
    [Bonaire.dsn, Bonaire.kicad_pcb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]
2019-07-18 Make changes to circuit boardq
    [Bonaire.dsn, Bonaire.kicad_pcb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]
2019-07-18 make sure board is updated
    [Bonaire.sch]
2019-07-22 got BME Sensor Working
2019-07-22 BME 680 and particulate sensor now.
2020-08-04 final commit
    [M12Hole.dxf, SensorCut.dxf]
2021-03-17 Add note about connector
